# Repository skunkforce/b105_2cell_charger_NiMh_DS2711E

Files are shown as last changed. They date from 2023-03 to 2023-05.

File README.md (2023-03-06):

# edgy_board number b105
This design is part of the [edgy board project](https://github.com/skunkforce/edgy_boards). 

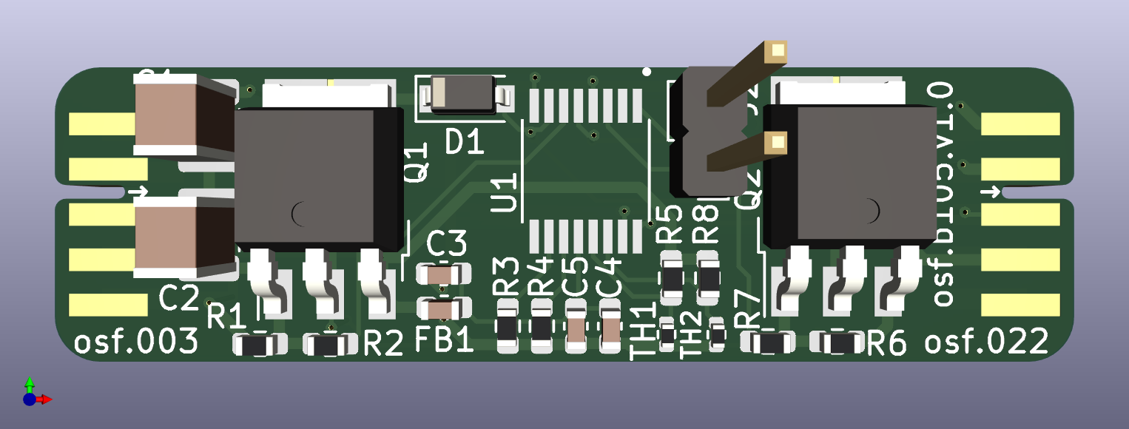
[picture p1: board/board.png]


# getting started
This repository uses submodules. After cloning use the command 

```$ git submodule update --init --recursive```

to pull the submodules before opening the project with kicad. 

# Tests
Tests can be found in [TESTS.md](TESTS.md)

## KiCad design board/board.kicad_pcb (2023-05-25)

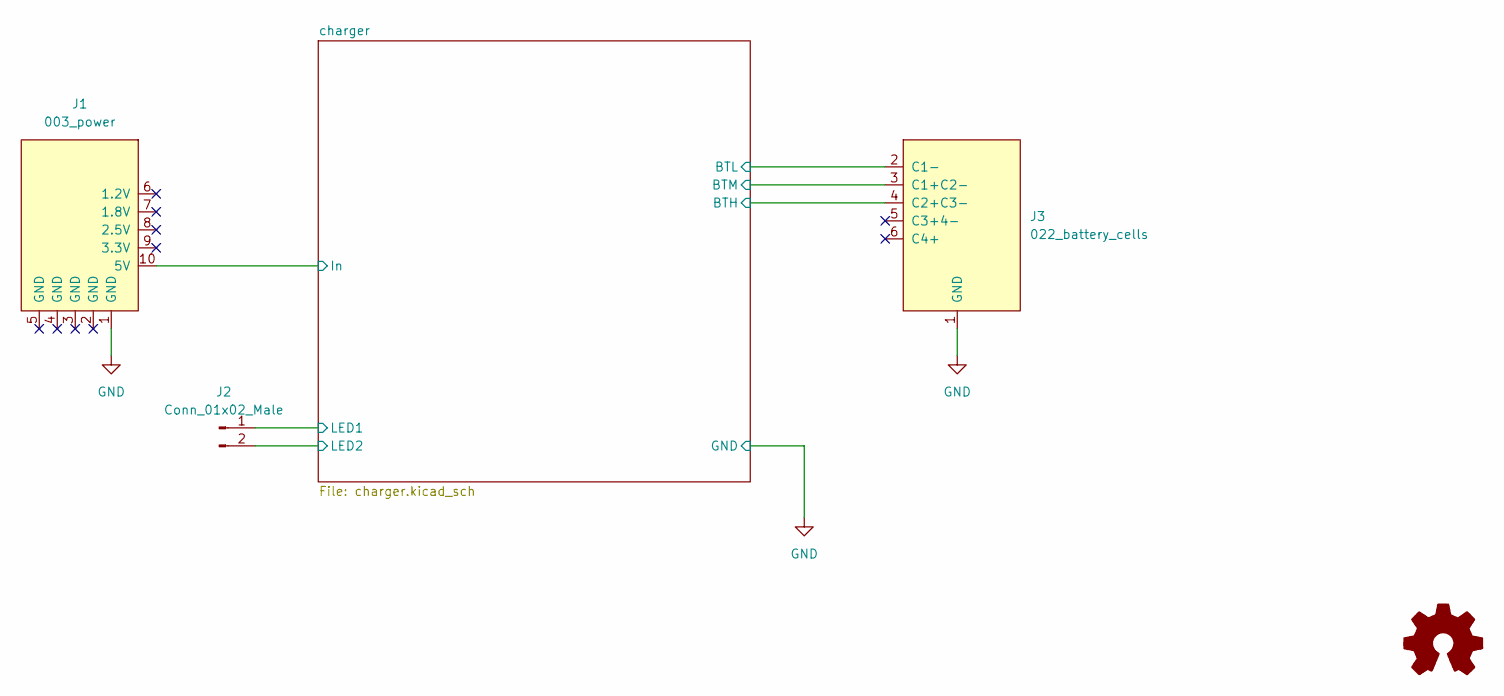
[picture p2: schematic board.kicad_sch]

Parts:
J1: 003_power; on_edge_2x05_device
J2: Conn_01x02_Male; PinHeader_1x02_P2.54mm_Vertical
J3: 022_battery_cells; on_edge_2x05_host
LOGO1: Logo_Open_Hardware_Small; OSHW-Symbol_6.7x6mm_SilkScreen

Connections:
/charger/BTH: J3.4 (C2+C3-); also elsewhere on the board
/charger/BTL: J3.2 (C1-); also elsewhere on the board
/charger/BTM: J3.3 (C1+C2-); also elsewhere on the board
/charger/In: J1.10 (5V); also elsewhere on the board
/charger/LED1: J2.1; also elsewhere on the board
/charger/LED2: J2.2; also elsewhere on the board
GND: J1.1 (GND), J3.1 (GND); also elsewhere on the board

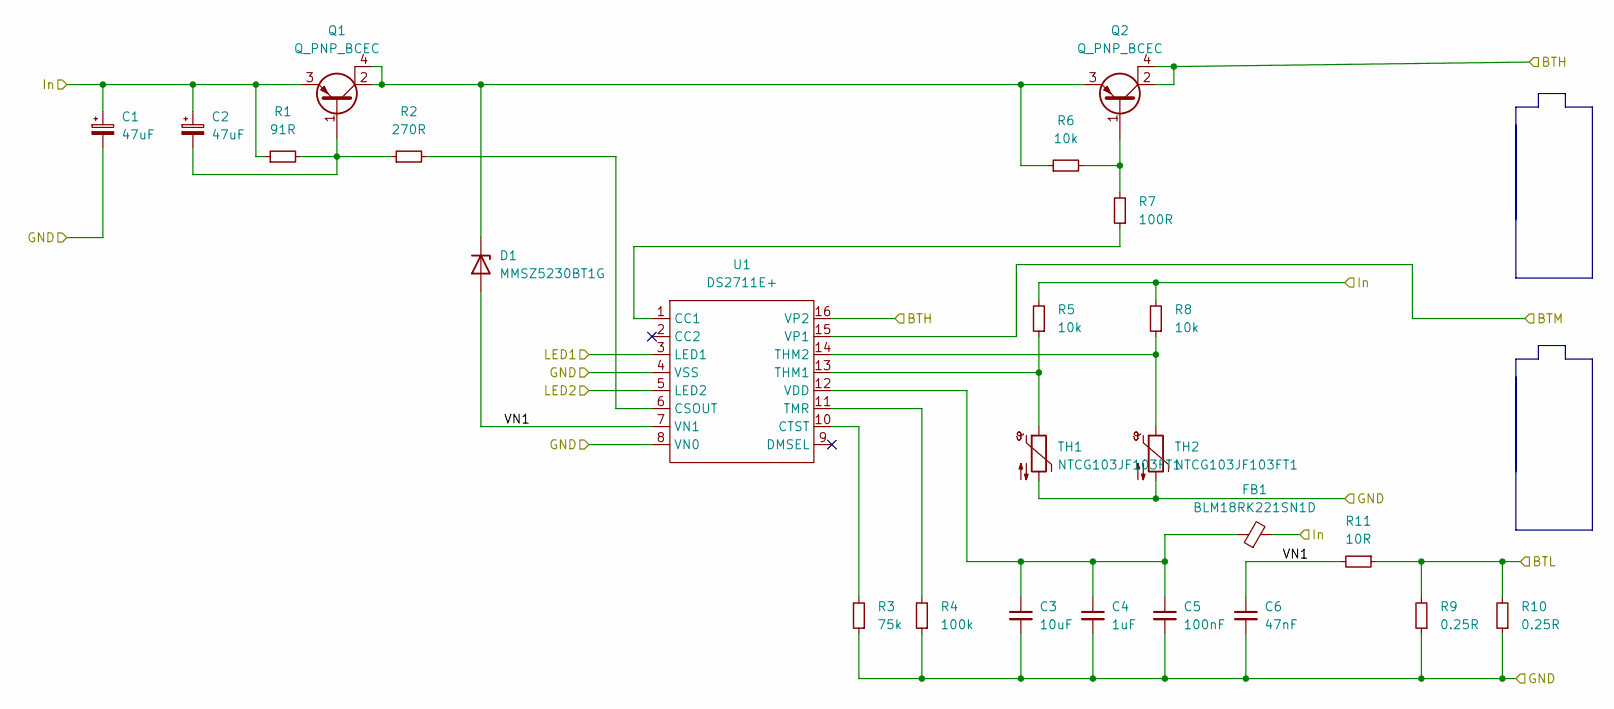
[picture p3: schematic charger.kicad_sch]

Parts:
C1, C2: 47uF; C_1210_3225Metric; MPN TAJB476K010RNJ
C3: 10uF; C_0603_1608Metric
C4: 1uF; C_0603_1608Metric
C5: 100nF; C_0603_1608Metric
C6: 47nF; C_0603_1608Metric
D1: MMSZ5230BT1G; D_SOD-123; MPN MMSZ5230BT1G
FB1: BLM18RK221SN1D; C_0603_1608Metric
Q1, Q2: Q_PNP_BCEC; TO-252-3_TabPin4; MPN MJD45H11T4G
R1: 91R; R_0603_1608Metric
R2: 270R; R_0603_1608Metric
R3: 75k; R_0603_1608Metric
R4: 100k; R_0603_1608Metric
R5, R6, R8: 10k; R_0603_1608Metric
R7: 100R; R_0603_1608Metric
R9, R10: 0.25R; R_1206_3216Metric
R11: 10R; R_0603_1608Metric
TH1, TH2: NTCG103JF103FT1; R_0402_1005Metric; MPN NTCG103JF103FT1
U1: DS2711E+; SOP65P640X110-16N; MPN DS2711E+

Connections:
/charger/BTH: Q2.2 (C), Q2.4 (C), U1.16 (VP2); also elsewhere on the board
/charger/BTL: R9.2, R10.2, R11.1; also elsewhere on the board
/charger/BTM: U1.15 (VP1); also elsewhere on the board
/charger/In: C1.1, C2.1, FB1.2, Q1.3 (E), R1.1, R5.2, R8.2; also elsewhere on the board
/charger/LED1: U1.3 (LED1); also elsewhere on the board
/charger/LED2: U1.5 (LED2); also elsewhere on the board
/charger/VN1: C6.1, D1.2 (A), R11.2, U1.7 (VN1)
GND: C1.2, C3.2, C4.2, C5.2, C6.2, R3.1, R4.1, R9.1, R10.1, TH1.2, TH2.2, U1.4 (VSS), U1.8 (VN0); also elsewhere on the board
unnamed: C2.2, Q1.1 (B), R1.2, R2.1
unnamed: C3.1, C4.1, C5.1, FB1.1, U1.12 (VDD)
unnamed: D1.1 (K), Q1.2 (C), Q1.4 (C), Q2.3 (E), R6.1
unnamed: Q2.1 (B), R6.2, R7.2
unnamed: R2.2, U1.6 (CSOUT)
unnamed: R3.2, U1.10 (CTST)
unnamed: R4.2, U1.11 (TMR)
unnamed: R5.1, TH1.1, U1.13 (THM1)
unnamed: R7.1, U1.1 (CC1)
unnamed: R8.1, TH2.1, U1.14 (THM2)

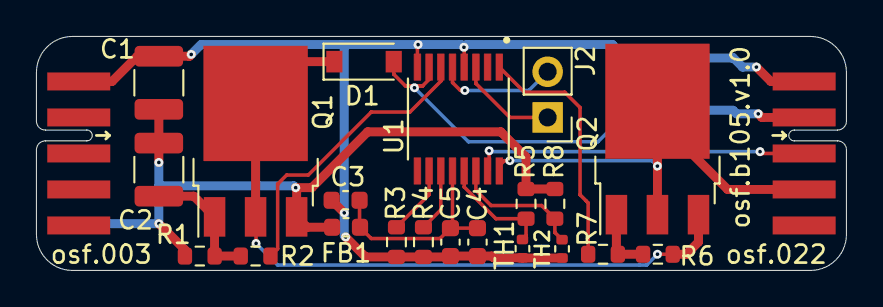
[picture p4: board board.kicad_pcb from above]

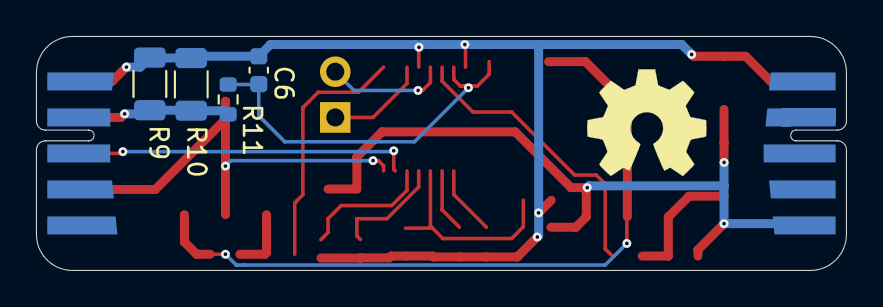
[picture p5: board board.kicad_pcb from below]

Board: 2 copper layers, 45.0 x 13.0 mm, 28 parts (5 on the bottom side), 18 nets.

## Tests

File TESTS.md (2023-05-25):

# charge test
## setup
Connected 
```mermaid
flowchart LR
  usb --> b051[osf.b051.v1.0]
  b051 --> b105[osf.b105.v1.0]
  b105 --> b117[osf.b117.v1.0]
```
loaded 2 cells and monitored the input energy.
## results
The two cells charged at roughly 400mW untill full. Once charging stopped the circuit used roughly 4mW.

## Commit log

2023-03-09 fixed missing connection
    [board.kicad_pcb, charger.kicad_sch]
2023-04-13 fixed footprint
    [board.kicad_pcb, board.kicad_sch, charger.kicad_sch]
2023-05-25 added missing limmiting resistor to protect zener diode
    [board.kicad_pcb, board.kicad_sch, charger.kicad_sch]
